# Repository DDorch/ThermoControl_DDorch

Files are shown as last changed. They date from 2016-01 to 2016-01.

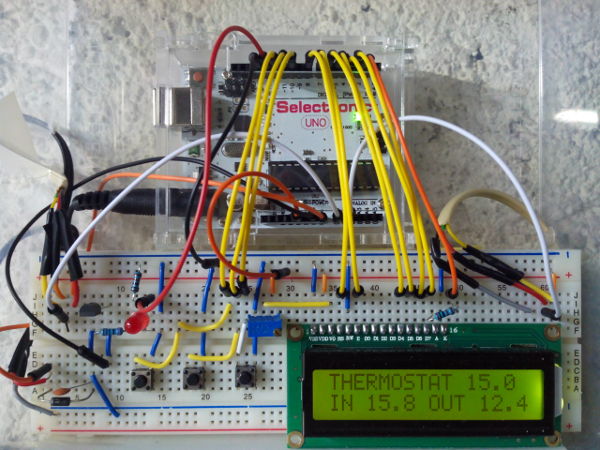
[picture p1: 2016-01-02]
wiki/photo_bb.jpg

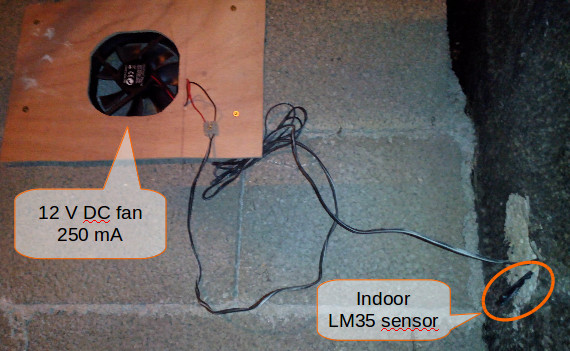
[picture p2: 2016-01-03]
wiki/photo_fan_LM35.jpg

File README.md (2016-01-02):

# ThermoControl_DDorch

This code is a C code made for fonctionning with Arduino Uno Hardware.

The aim of this project is to regulate an indoor temperature using ventilation with outdoor temperature. The program control if the temperature is favourable and run the fan consequently.

The hardware is mainly composed of:
- 1 Arduino Uno
- 1 Hitachi HD44780 LCD controller
- 2 LM35 temperature sensors
- 3 press buttons
- 1 BC547 transistor
- 1 led
- 1 10 kΩ variable resistor
- 2 1 kΩ resistor
- 1 220 Ω resistor

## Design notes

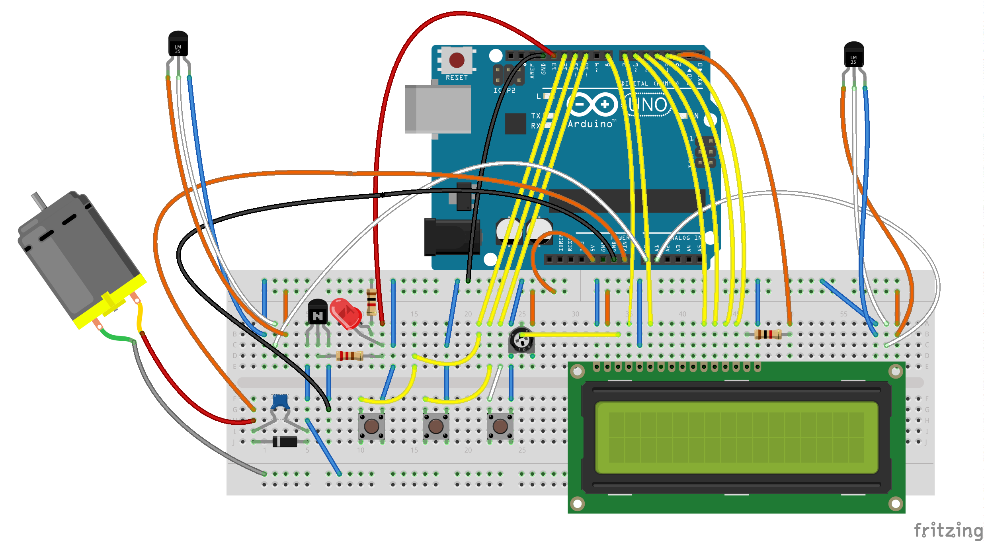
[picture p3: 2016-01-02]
wiki/thermocontrol_bb.png

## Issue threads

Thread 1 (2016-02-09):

avoid alternate fan on/off at close temperature

DDorch, 2016-02-09:
Due to temperature instability the fan can switch on and off when temperatures are close to the limites of switching.
By counting a minimum of consecutive temperatures matching for switch, we can avoid the switch alternance in that case.

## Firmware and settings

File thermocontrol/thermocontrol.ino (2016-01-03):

/**
  @file termocontrol.ino
  Thermo regulator
  @author David Dorchies
  @date 27/12/2015
  @version 1.0.0
 
  The circuit:
  Connections to LCD 2x16 display :
  - LCD VSS to ground
  - LCD VDD to +5V
  - LCD VO to adjustable resistor
  - LCD RS pin to digital pin 8
  - LCD R/W pin to ground
  - LCD Enable pin to digital pin 7
  - LCD D4 pin to digital pin 6
  - LCD D5 pin to digital pin 5
  - LCD D6 pin to digital pin 4
  - LCD D7 pin to digital pin 3
  - LCD A pin to digital pin 2 with 1K Ohm resistance
  - LCD K pin to ground
  Connections to 2xLM35
  - LM35 inside to analog 0
  - LM35 ouitside to analog 1
  Connections to pushbuttons
  - Push button Set to digital 12
  - Push button Plus to digital 11
  - Push button Minus to digital 10
  Connection to 12V Fan supplied by Vin pin
  - BC547 Base to digital pin 13 through LED + 220 Ohm
 */

// include the libraries 
#include <LiquidCrystal.h>
#include <EEPROM.h>

// DEBUG : uncomment the next line for getting debug print on serial
//#define _DEBUG_

#ifdef _DEBUG_
#define _DBG_INIT_ Serial.begin(9600)
#define _DBG_PRINT_(s) Serial.print(String(ulTime)+": ");Serial.println(s)
#else
#define _DBG_INIT_
#define _DBG_PRINT_(s) 
#endif

// Connections parameters
int aiAPTemp[2] = {0,1}; // Analogic Pin for LM35  inside[0] and outside[1]
int iDPFan = 13; // Digital Pin for fan trigger control
int iDPBtnMode = 12; // Digital Pin of "Set" button
int iDPBtnMinus = 11; // Digital Pin of "Minus" button
int iDPBtnPlus = 10; // Digital Pin of "Plus" Button
int iDPLcdLight = 2; // Digital Pin of LCD A pin for LCD light

// Program parameters
unsigned long iTempoMode = 10000; // Set tempo for returning to mode zero in milliseconds
unsigned long iButtonDelay = 500; // delay between push actions in milliseconds
unsigned long iMeasureDelay = 10; // delay between measurements in milliseconds 
unsigned long iDisplayDelay = 2000; // Delay between measurements displays in milliseconds 
const int NB_STORAGE = 50; // Number of time steps stores in memory
unsigned long iAutoRollDisp = 2000; // Delay for autoroll display of stored temperatures in milliseconds

// Program control variables
boolean bButtonMode = false; // true if the button is pushed
boolean bButtonPlus = false; // true if the button is pushed
boolean bButtonMinus = false; // true if the button is pushed
boolean bButtonReady = true; // true if the push button can be handled
boolean bUpdateDisp = true; // true if the temperature display should be updated
boolean bFanOn = false; // Control of fan
boolean bLcdOn = true; // Control of LCD
unsigned long ulTime; // Current Millis
unsigned long ulLightOff; // Millis when light will switch off
unsigned long ulFanReady; // Millis when fan will be able to start/stop (10 sec. from starting arduino)
unsigned long ulModeEnd = 0; // Millis when the function mode will return to zero
unsigned long ulButtonReady = 0; // Millis when a new action could be handle by pushing a button
unsigned long ulMeasure = 0; // Millis when next reading of temperatures
unsigned long ulDisplayTemp = 0; // Millis when next display of temperatures
unsigned long ulStore = 0; // Millis when next data calculation and store
unsigned long ulAutoRollDisp = 0; // Millis when next update of autoroll display
unsigned long ulFanLastStart = 0; // Millis when the fan started last time

/** 
 * Function mode
 * - 0 : Display temperature (Current / Mini / Maxi)
 * - 1 : Display stored mean temperatures
 * - 2 : Fan run stats
 * - 3 : Set target temperature (°C)
 * - 4 : Set minimum delta temperature to fan (°C)
 * - 5 : Set temporisation for fan (sec.)
 * - 6 : Set temporisation for light (sec.)
 * - 7 : Set storage time step
 */
int iMode=0;
// Display Mode
// - 0 : Current temperatures + Target
// - 1 : Minimum temperatures
// - 2 : Maximum temperatures
int iDisp=0;

// Measures
unsigned long aMeasures[2] = {0, 0}; // Sum of temperatures for mean calculation of display temp
word nMeasures = 0; // Count of read measurements for mean calculation of display temp
word aTemp[2]; // Temperature 1/10 °C inside[0] and outside[1]
word aTempMin[2] = {1000, 1000}; // Minimum temperature inside[0] and outside[1]
word aTempMax[2] = {0, 0}; // Maximum temperature inside[0] and outside[1]
unsigned long nTempMean = 0; // count the number of records for mean calculation
unsigned long ulTempSum[2] = {0, 0}; // Sum the temperatures for mean calculation of stored temp

// EEPROM stored variables
const byte byteMagicKey = 181; // MagicKey that should be in first byte of EEPROM to considere reading it
struct eeprom_t {
  word tempTarget = 160; // Target temperature in 1/10 °C
  byte tempDelta = 5; // Minimum delta temp between in & out to fan in 1/10 °C
  unsigned long iTempoFan = 60000; // Fan temporisation for start/stop in milliseconds
  unsigned long iTempoLCD = 120000; // LCD Light temporisation  in milliseconds
  unsigned long iStoreTimeStep = 3600000; // Temperature storage time step in milliseconds
  word aTempMean[2*NB_STORAGE]; // Storage of mean temperature during 50 last storage time step [2n] inside and [2n+1] outside
  word anFanStarts[NB_STORAGE]; // count the number of fan starts by storage time step
  word aiFanRunTime[NB_STORAGE]; // Time of fan run time for each storage time step
} e;

// initialize the library with the numbers of the interface pins
LiquidCrystal lcd(8, 7, 6, 5, 4, 3); // LiquidCrystal(rs, enable, d4, d5, d6, d7)


void setup() {
  _DBG_INIT_;      // when _DEBUG is defined, open the serial port at 9600 bps:
  digitalWrite(iDPLcdLight,HIGH);
  // set up the LCD's number of columns and rows: 
  lcd.begin(16, 2);
  //lcd.noCursor();
  // Print a message to the LCD.
  lcd.print("Initialisation");
  // Set Digital Pins for push button in pullup mode. See https://www.arduino.cc/en/Tutorial/InputPullupSerial
  pinMode(iDPFan,OUTPUT);
  pinMode(iDPBtnMode, INPUT_PULLUP);    
  pinMode(iDPBtnMinus, INPUT_PULLUP);   
  pinMode(iDPBtnPlus, INPUT_PULLUP);
  pinMode(iDPLcdLight, OUTPUT);
  analogReference(INTERNAL); // Set Analog Voltage to 1.1V. See http://playground.arduino.cc/Main/LM35HigherResolution
  lcd.setCursor(0,1);
  lcd.print("Sensors");
  stabiliseMeasures(); // For avoiding artefic measurement due to voltage change
  delay(iDisplayDelay);
  lcd.setCursor(0,1);
  if(digitalRead(iDPBtnMode)!=LOW) {
    // Reading saved data in EEPROM
    byte byteKey;
    EEPROM.get(0,byteKey);
    if(byteKey == byteMagicKey) {
      // The first byte match the magic key, we can read data !
      lcd.print("Reading EEPROM");
      EEPROM.get(1,e);
    } else {
      lcd.print("Default settings");
    }
  } else {
    lcd.print("Reset settings");
  }
  delay(2000);
  ulTime = millis();
  ulStore = ulTime + e.iStoreTimeStep;
  ulLightOff = ulTime + e.iTempoLCD;
  ulFanReady = ulTime + e.iTempoFan;
}


void loop() {

  // Set current time
  ulTime = millis();

  // Read buttons values 
  unsigned long ulButtonPressed = ulTime + 50; // Button press accepted after 5/100 sec.
  do {
    bButtonMode = (digitalRead(iDPBtnMode)==LOW);
    bButtonPlus = (digitalRead(iDPBtnPlus)==LOW);
    bButtonMinus = (digitalRead(iDPBtnMinus)==LOW);
  } while((bButtonMode || bButtonPlus || bButtonMinus) && (ulButtonPressed > millis()));
  
  // Control function time out
  if(ulModeEnd < ulTime && iMode > 0) {
    iMode = 0;
    iDisp = 0;   
    storeEEPROM();
    bUpdateDisp=true;
  }
  
  // Measurement
  if(ulMeasure < ulTime) {
    for(int i=0; i<2; i++) {
      aMeasures[i] += analogRead(aiAPTemp[i]);
    }
    nMeasures += 1;
    ulMeasure = ulTime + iMeasureDelay;
  }
  
  // Control temperature and fan start/stop
  if(ulDisplayTemp < ulTime) {
    // Temperature measurement. See http://playground.arduino.cc/Main/LM35HigherResolution
    if(nMeasures > 100) {
      float conv = 1 / (nMeasures * 0.931);
      for(int i=0; i<2; i++) {        
        aTemp[i] = aMeasures[i] * conv;
        // Update Min/Max
        if(aTemp[i] < aTempMin[i]) aTempMin[i] = aTemp[i];
        if(aTemp[i] > aTempMax[i]) aTempMax[i] = aTemp[i];
        // Mean calculation
        ulTempSum[i] += aTemp[i];
        aMeasures[i] = 0;
      }
      nMeasures = 0;
      nTempMean++;
      ulDisplayTemp = ulTime + iDisplayDelay;
      if(iMode==0) bUpdateDisp = true;
      
      // Control fan
      if(ulFanReady < ulTime) {
        // Correction of temp out respect to minimum delta temp
        word tempOutCor; // Corrected temp out with delta
        if(aTemp[0]>e.tempTarget) {
          tempOutCor = aTemp[1] + e.tempDelta;
        }else {
          tempOutCor = aTemp[1] - e.tempDelta;
        }
        _DBG_PRINT_("In "+String(aTemp[0])+" OutCor "+String(tempOutCor));
        if((aTemp[0] > tempOutCor)^(aTemp[0] < e.tempTarget)) {
          if(!bFanOn) switchFan();
        }
        else if (bFanOn) {
          switchFan();
        }
      }
    }
  }
  
  // Calculate and store mean temperature and fan stats
  if(ulStore < ulTime && nTempMean > 0) {
    // Temperatures
    for(int i=0; i<2; i++) {
      for(int j=NB_STORAGE-1; j>0; j--) {
        e.aTempMean[2*j+i] = e.aTempMean[2*(j-1)+i];
      }
      e.aTempMean[i] = ulTempSum[i] / nTempMean;
      ulTempSum[i] = 0;
    }
    nTempMean = 0;
    // Fan stats
    if(bFanOn) {
      e.aiFanRunTime[0] += (ulTime - ulFanLastStart)/1000;
      ulFanLastStart = ulTime;
    }
    for(int j=NB_STORAGE-1; j>0; j--) {
      e.anFanStarts[j] = e.anFanStarts[j-1];
      e.aiFanRunTime[j] = e.aiFanRunTime[j-1];
    }
    e.anFanStarts[0] = 0;
    e.aiFanRunTime[0] = 0;
    storeEEPROM();
    ulStore = ulTime + e.iStoreTimeStep;
  }
  
  // Autoroll display for stared mean temperatures and fan stats
  if((iMode == 1 || iMode == 2) && ulAutoRollDisp < ulTime) {
    iDisp += 1;
    if(iDisp > NB_STORAGE-1) iDisp = 1;
    bUpdateDisp = true;
  }

  // Control LCD display and function to display
  if((bButtonMode || bButtonPlus || bButtonMinus) && ulButtonReady < ulTime) {

    // Manage times out
    ulButtonReady = ulTime + iButtonDelay; // A button was pressed and can be handled => Set the next idle time
    ulModeEnd = ulTime + iTempoMode; // Postpone the tempo for returning to display mode
    ulLightOff = ulTime + e.iTempoLCD; // Update time for switching off

    // Control LCD light
    if(!bLcdOn) {
      switchLCD(true);
      return; // the key press only switch on the LCD
    }    
    
    if(bButtonMode) {
      // Set button pushed => Change fonction
      iMode += 1;
      iDisp = 0; // Reset Disp Mode
      if(iMode > 7) iMode=0;
    }
    if(iMode == 1 || iMode == 2) {
      // Postpone the tempo for returning to display mode : special time for autoroll
      ulModeEnd = ulTime + (NB_STORAGE)*iAutoRollDisp;
    }
   
  } else if(!bUpdateDisp) {
    // Control light switch off
    if(ulLightOff < ulTime && bLcdOn) {
      // Switch the display off
      switchLCD(false);
    }
    // No order to be handled => Stop here
    return;
  } else {
    // Button press is not valid (ulButtonReady > ulTime)
    bButtonMode = false;
    bButtonPlus = false;
    bButtonMinus = false;
  }

  // Run functions 
  if((bButtonMode || bButtonPlus || bButtonMinus) || bUpdateDisp) {

    bUpdateDisp = false;
    switch(iMode) {
      case 0:
        // Display Mode
        if(bButtonPlus) {
          iDisp +=1;
          if(iDisp > 2) iDisp = 0;
        }
        if(bButtonMinus) {
          iDisp -=1;
          if(iDisp < 0) iDisp = 2;
        }
        if(bButtonPlus && bButtonMinus) {
          // Reset min & max
          for(int i=0; i<2; i++) {
            aTempMin[i] = aTemp[i];
            aTempMax[i] = aTemp[i];
          }
          displayTemp("RESET MINI MAXI", aTemp);
        } else {
          switch(iDisp) {
            case 0:
              // Display In/Out/Target Temperature
              displayTemp("THERMOSTAT "+tempToString(e.tempTarget), aTemp);
              break;
            case 1:
              // Display Minimum Temperatures
              displayTemp("TEMPERATURE MINI", aTempMin);
              break;
            case 2:
              // Display Maximum Temperatures
              displayTemp("TEMPERATURE MAXI", aTempMax);
              break;
          }
        }
        break;
        
      case 1:
      case 2:
        // Display stored mean temperatures
        if(iDisp < 0) iDisp = 0;
        if(bButtonPlus) {
          iDisp +=1;
          if(iDisp > NB_STORAGE-1) iDisp = 0;
        }
        if(bButtonMinus) {
          iDisp -=1;
          if(iDisp < 0) iDisp = NB_STORAGE-1;
        }
        if(iMode==1) {
          if(e.aTempMean[2*iDisp] == 0) iDisp = 0;
          displayTemp("Mean Temp "+timeToString((iDisp+1)*e.iStoreTimeStep), &e.aTempMean[2*iDisp]);
        } else {
          lcd.clear();
          lcd.print("Fan runs "+timeToString(iDisp*e.iStoreTimeStep));
          lcd.setCursor(0,1);
          lcd.print("Nb.: "+String(e.anFanStarts[iDisp]));
          lcd.print(" - "+timeToString((unsigned long)e.aiFanRunTime[iDisp]*1000));
        }
        ulAutoRollDisp = ulTime + iAutoRollDisp;
        break;
      case 3:
        // Set Target temperature
        e.tempTarget = setTemperature("SET THERMOSTAT", e.tempTarget);
        break;
      case 4:
        // Set MinDelta temperature for running fan
        e.tempDelta = setTemperature("DELTA MIN TEMP.", e.tempDelta);
        break;
      case 5:
        // Set fan temporisation 
        if(bButtonPlus && bButtonMinus) {
          // Manually switch the fan
          switchFan();
        } else {
          e.iTempoFan = setTemporisation("SET TEMPO FAN", e.iTempoFan);
        }
        break;
      case 6:
        // Set LCD temporisation 
        e.iTempoLCD = setTemporisation("SET TEMPO LCD", e.iTempoLCD);
        break;
      case 7:
        // Set Storage time step
        e.iStoreTimeStep = setTemporisation("STORE TIME STEP", e.iStoreTimeStep);
        ulStore = ulTime + e.iStoreTimeStep;
    }
  } 
}


/** 
 * Convert temperature in 1/10 °C to string in °C
 * @param temp in 1/10 °C
 * @return string of formated temperature with 1 decimals
 * @author David Dorchies
 * @date 28/12/2015
 */
String tempToString(word temp){
  byte intPart = temp/10;
  return String(intPart) + "." + String(temp - intPart * 10);
}


/** 
 * Convert time to string
 * @param time time in millisecondes
 * @return string in format 00d00h00m00s with only time units different to zero
 * @author David Dorchies
 * @date 29/12/2015
 */
String timeToString(unsigned long time) {
  unsigned long aulTS[4] = {86400, 3600, 60, 1};
  char acTS[5] = "dhms";
  String sT = "";
  int iT = 0;
  time = time / 1000;
  for(int i=0; i<4; i++) {
    if(time >= aulTS[i]) {
      iT = time / aulTS[i];
      if(iT<10) sT = sT + "0";
      sT = sT + iT;
      sT = sT + acTS[i];
      time = time - iT * aulTS[i];
    }
  }
  return sT;
}


/**
 * Display temperatures
 * @param sMode
 * @param aT[2] Temperatures to display  inside[0] and outside[1]
 * @param tempOut
 * @author David Dorchies
 * @date 28/12/2015
 */
void displayTemp(String sMode, word aT[]) {
  lcd.clear();
  lcd.print(sMode);
  lcd.setCursor(0, 1);
  lcd.print("IN "+tempToString(aT[0])+" OUT "+tempToString(aT[1]));
}


/**
 * Read measurement multiple times for stabilisation
 */
void stabiliseMeasures() {
  int temp;
  // First measures after changing analog ref are not accurate
  for(int i=0; i<100; i++) {
    for(int j=0; i<2; i++) {
      temp = analogRead(aiAPTemp[j]);
    }
  }
  ulMeasure = ulTime + iDisplayDelay;
}


/*
 * Display and set temperature with Minus and Plus buttons
 * @param sName Label to display in first row
 * @param temp Temperature to change
 * @author David Dorchies
 * @date 29/12/2015
 */
word setTemperature(String sName, word temp) {
  if(bButtonPlus) temp += 5;
  if(bButtonMinus) temp -= 5;
  if(temp < 0) temp = 0 ;
  // Display Maximum Temperatures
  lcd.clear();
  lcd.print(sName);
  lcd.setCursor(0, 1);
  lcd.print(tempToString(temp));
  return temp;
}


/**
 * Display and set temporisation with Minus and Plus buttons
 * using adaptable time steps
 * @param sName Label to display in first row
 * @param temp Temperature to change
 * @author David Dorchies
 * @date 29/12/2015
 */
unsigned long setTemporisation(String sName, unsigned long ulTempo) {
  unsigned long aulStep[] = {30,60,300,900,3600};
  int iStep;
  for(iStep=1; iStep<6; iStep++) {
    if(bButtonPlus && ulTempo < aulStep[iStep]*1000) break;
    if(bButtonMinus && ulTempo <= aulStep[iStep]*1000) break;
  }
  if(bButtonPlus) ulTempo += aulStep[iStep-1]*1000;
  if(bButtonMinus) ulTempo -= aulStep[iStep-1]*1000;
  if(ulTempo < 30000) ulTempo = 30000 ;
  // Display Maximum Temperatures
  lcd.clear();
  lcd.print(sName);
  lcd.setCursor(0, 1);
  lcd.print(timeToString(ulTempo));
  return ulTempo;
}


/**
 * Switch the fan on and off
 * @author David Dorchies
 * @date 31/12/2015
 */
void switchFan() {
  if(!bFanOn) {
    // Switch on the fan
    _DBG_PRINT_("Fan ON");
    digitalWrite(iDPFan,HIGH);
    ulFanLastStart = ulTime;
    e.anFanStarts[0] += 1;
  } else {
    // Switch off the fan
    _DBG_PRINT_("Fan OFF");
    digitalWrite(iDPFan,LOW);
    e.aiFanRunTime[0] += (ulTime - ulFanLastStart)/1000;
  }
  bFanOn = !bFanOn;
  ulFanReady = ulTime + e.iTempoFan;
  if(!bLcdOn) switchLCD(true);
  stabiliseMeasures(); // For avoiding artifac measurement due to voltage change
}


/**
 * Switch the LCD on and off
 * @param bLcd switch the LCD screen (true=on, false=off)
 * @author David Dorchies
 * @date 01/01/2016
 */
void switchLCD(boolean bLcd) {
  if(bLcd) {
    digitalWrite(iDPLcdLight,HIGH);
    lcd.display();
    ulLightOff = ulTime + e.iTempoLCD; // Update time for switching off
  } else {
    digitalWrite(iDPLcdLight,LOW);
    lcd.noDisplay();
    // Reset interface
    iMode = 0;
    iDisp = 0;
  }
  bLcdOn = bLcd;
  stabiliseMeasures(); // For avoiding artefic measurement due to voltage change
}

/** 
 *  Store configuration and statistics in EEPROM using EEPROM library (need Arduino IDE >= 1.6.2)
 */
void storeEEPROM() {
  lcd.clear();
  lcd.print("Writing EEPROM");
  EEPROM.put(0, byteMagicKey);
  EEPROM.put(1,e);
}

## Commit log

2016-01-02 Adding Fritzing file
    [thermocontrol.fzz]
2016-01-03 Updating photos for wiki
    [thermocontrol.fzz]
